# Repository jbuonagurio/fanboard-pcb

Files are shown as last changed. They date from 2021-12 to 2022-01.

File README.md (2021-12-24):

# Fan Control Board Hardware Design

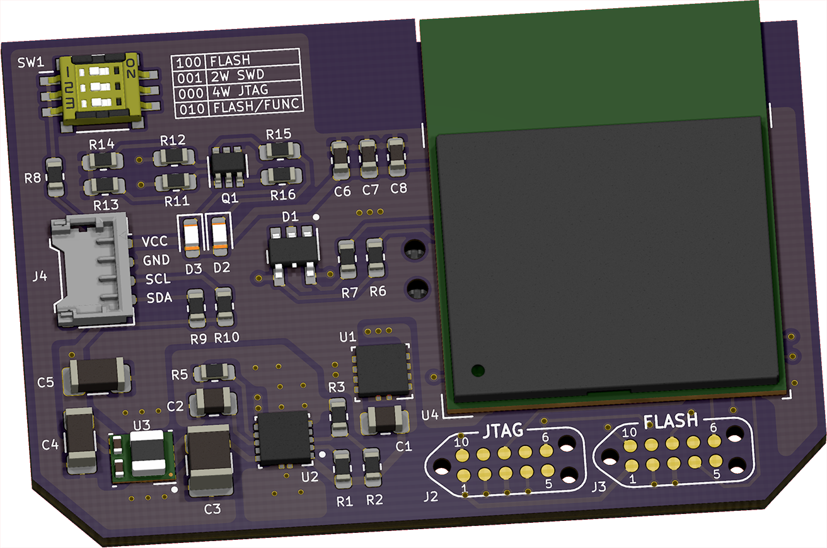
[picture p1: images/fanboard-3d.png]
3D View


## Schematic

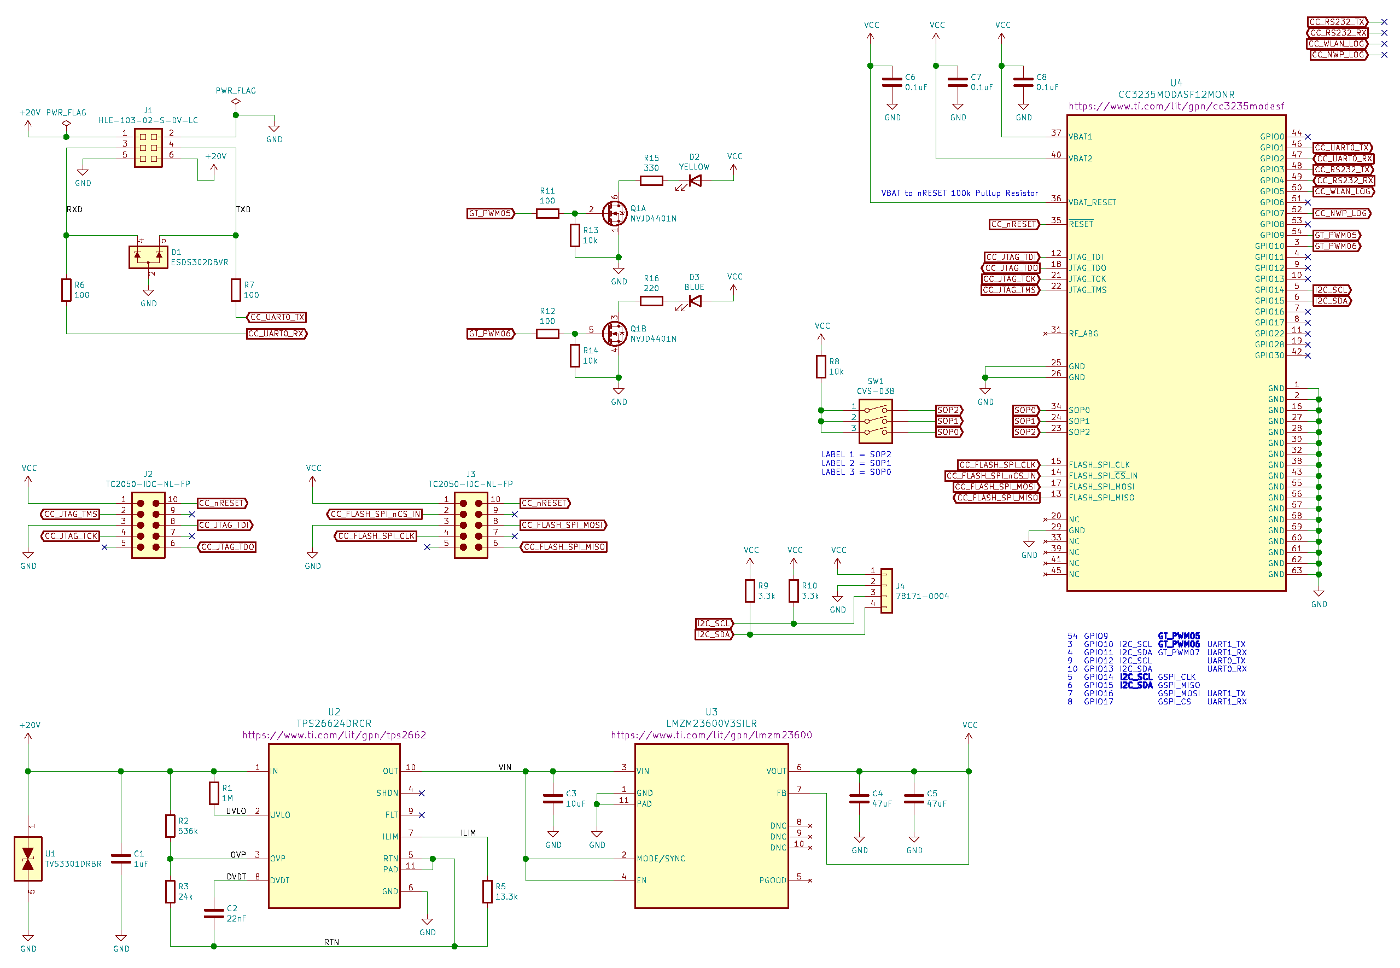
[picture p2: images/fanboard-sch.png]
Schematic


## Bill of Materials

| Designator | Quantity | Description | Manufacturer | Manufacturer Part Number | Digi-Key Part Number | 
|:---|:---:|:---|:---|:---|:---|
| SW1 | 1 | DIP Switch SPST 3 Position 1mm Pitch 100mA 6V | Nidec Copal | CVS-03TB | 563-1194-1-ND | 
| U1 | 1 | 33V Bidirectional Flat-Clamp Surge Protection Device | Texas Instruments | TVS3301DRBR | 296-53063-1-ND | 
| U2 | 1 | 60V 800mA Industrial eFuse with Integrated Input and Output Reverse Polarity Protection | Texas Instruments | TPS26624DRCR | 296-TPS26624DRCRCT-ND | 
| U3 | 1 | Non-Isolated PoL Module DC DC Converter Output 3.3V 500mA Input 4V-36V | Texas Instruments | LMZM23600V3SILT | 296-49458-1-ND | 
| U4 | 1 | Dual-Band Wireless MCU Module | Texas Instruments | CC3235MODASF12MONR | 296-CC3235MODASF12MONRCT-ND | 
| C1 | 1 | Ceramic Capacitor 1 μF 50V X7R 0805 ±10% | KEMET | C0805C105K5RACTU | 399-7409-1-ND | 
| C2 | 1 | Ceramic Capacitor 0.0022 μF (2200 pF) 50V C0G/NP0 0805 ±1% | KEMET | C0805C222F5GACTU | 399-11167-1-ND | 
| C3 | 1 | Ceramic Capacitor 10 μF 50V X7R 1210 ±10% | KEMET | C1210C106K5RACTU | 399-11629-1-ND | 
| C4 C5 | 2 | Ceramic Capacitor 47 μF 10V X5R 1206 ±20% | KEMET | C1206C476M8PACTU | 399-5508-1-ND | 
| C6 C7 C8 | 3 | Ceramic Capacitor 0.1 μF 10V X7R 0603 ±10% | KEMET | C0603C104K8RACTU | 399-1095-1-ND | 
| D1 | 1 | ESD Protection Diode Dual 2.3 pF 3.6V ±30kV SOT23-5 | Texas Instruments | ESDS302DBVR | 296-51110-1-ND | 
| D2 | 1 | Yellow 590nm LED Indication 1.85V 0603 (1608 Metric) | Kingbright | APT1608LSYCK/J3-PRV | 754-1932-1-ND | 
| D3 | 1 | Blue 470nm LED Indication 2.65V 0603 (1608 Metric) | Kingbright | APT1608LVBC/D | 754-1933-1-ND | 
| J1 	 | 1	 | HLE Socket 2.54mm Pitch 6 Position 30μ" Selective Gold Locking Clip | Samtec | HLE-103-02-S-DV-LC | HLE-103-02-S-DV-LC-ND |
| J4 | 1 | Pico-EZmate Header 1.20mm Pitch 4 Position | Molex | 078171-0004 | WM4460CT-ND | 
| Q1 | 1 | MOSFET Dual N-Channel Small Signal ESD Protection 20V 630mA SC-88 | onsemi | NVJD4401NT1G | NVJD4401NT1GOSCT-ND | 
| R1 | 1 | Resistor 1 MΩ 1/10W 0603 ±0.5% Thin Film | Yageo | RT0603DRD071ML | 13-RT0603DRD071MLCT-ND | 
| R9 R10 | 2 | Resistor 3.3 kΩ 1/10W 0603 ±5% | Vishay Dale | CRCW06033K30JNEAC | 541-CRCW06033K30JNEACCT-ND  | 
| R15 | 1 | Resistor 330 Ω 1/10W 0603 ±1% | Vishay Dale | CRCW0603330RFKEA | 541-330HCT-ND | 
| R16 | 1 | Resistor 220 Ω 1/10W 0603 ±1% | Vishay Dale | CRCW0603220RJNEA | 541-220GCT-ND | 
| R2 | 1 | Resistor 536 kΩ 1/10W 0603 ±0.1% Thin Film | Yageo | RT0603BRD07536KL | 13-RT0603BRD07536KLCT-ND | 
| R3 | 1 | Resistor 24 kΩ 1/10W 0603 ±0.5% Thin Film | Yageo | RT0603DRD0724KL | 311-24KDCT-ND | 
| R5 | 1 | Resistor 13.3 kΩ 1/10W 0603 ±0.5% Thin Film | Yageo | RT0603DRD0713K3L | 311-13.3KDCT-ND | 
| R6 R7 R11 R12 | 4 | Resistor 100 Ω 1/10W 0603 ±1% | Vishay Dale | CRCW0603100RFKEAC | 541-3951-1-ND | 
| R8 R13 R14 | 3 | Resistor 10 kΩ 1/10W 0603 ±1% | Vishay Dale | CRCW060310K0FKEAC | 541-5136-1-ND |

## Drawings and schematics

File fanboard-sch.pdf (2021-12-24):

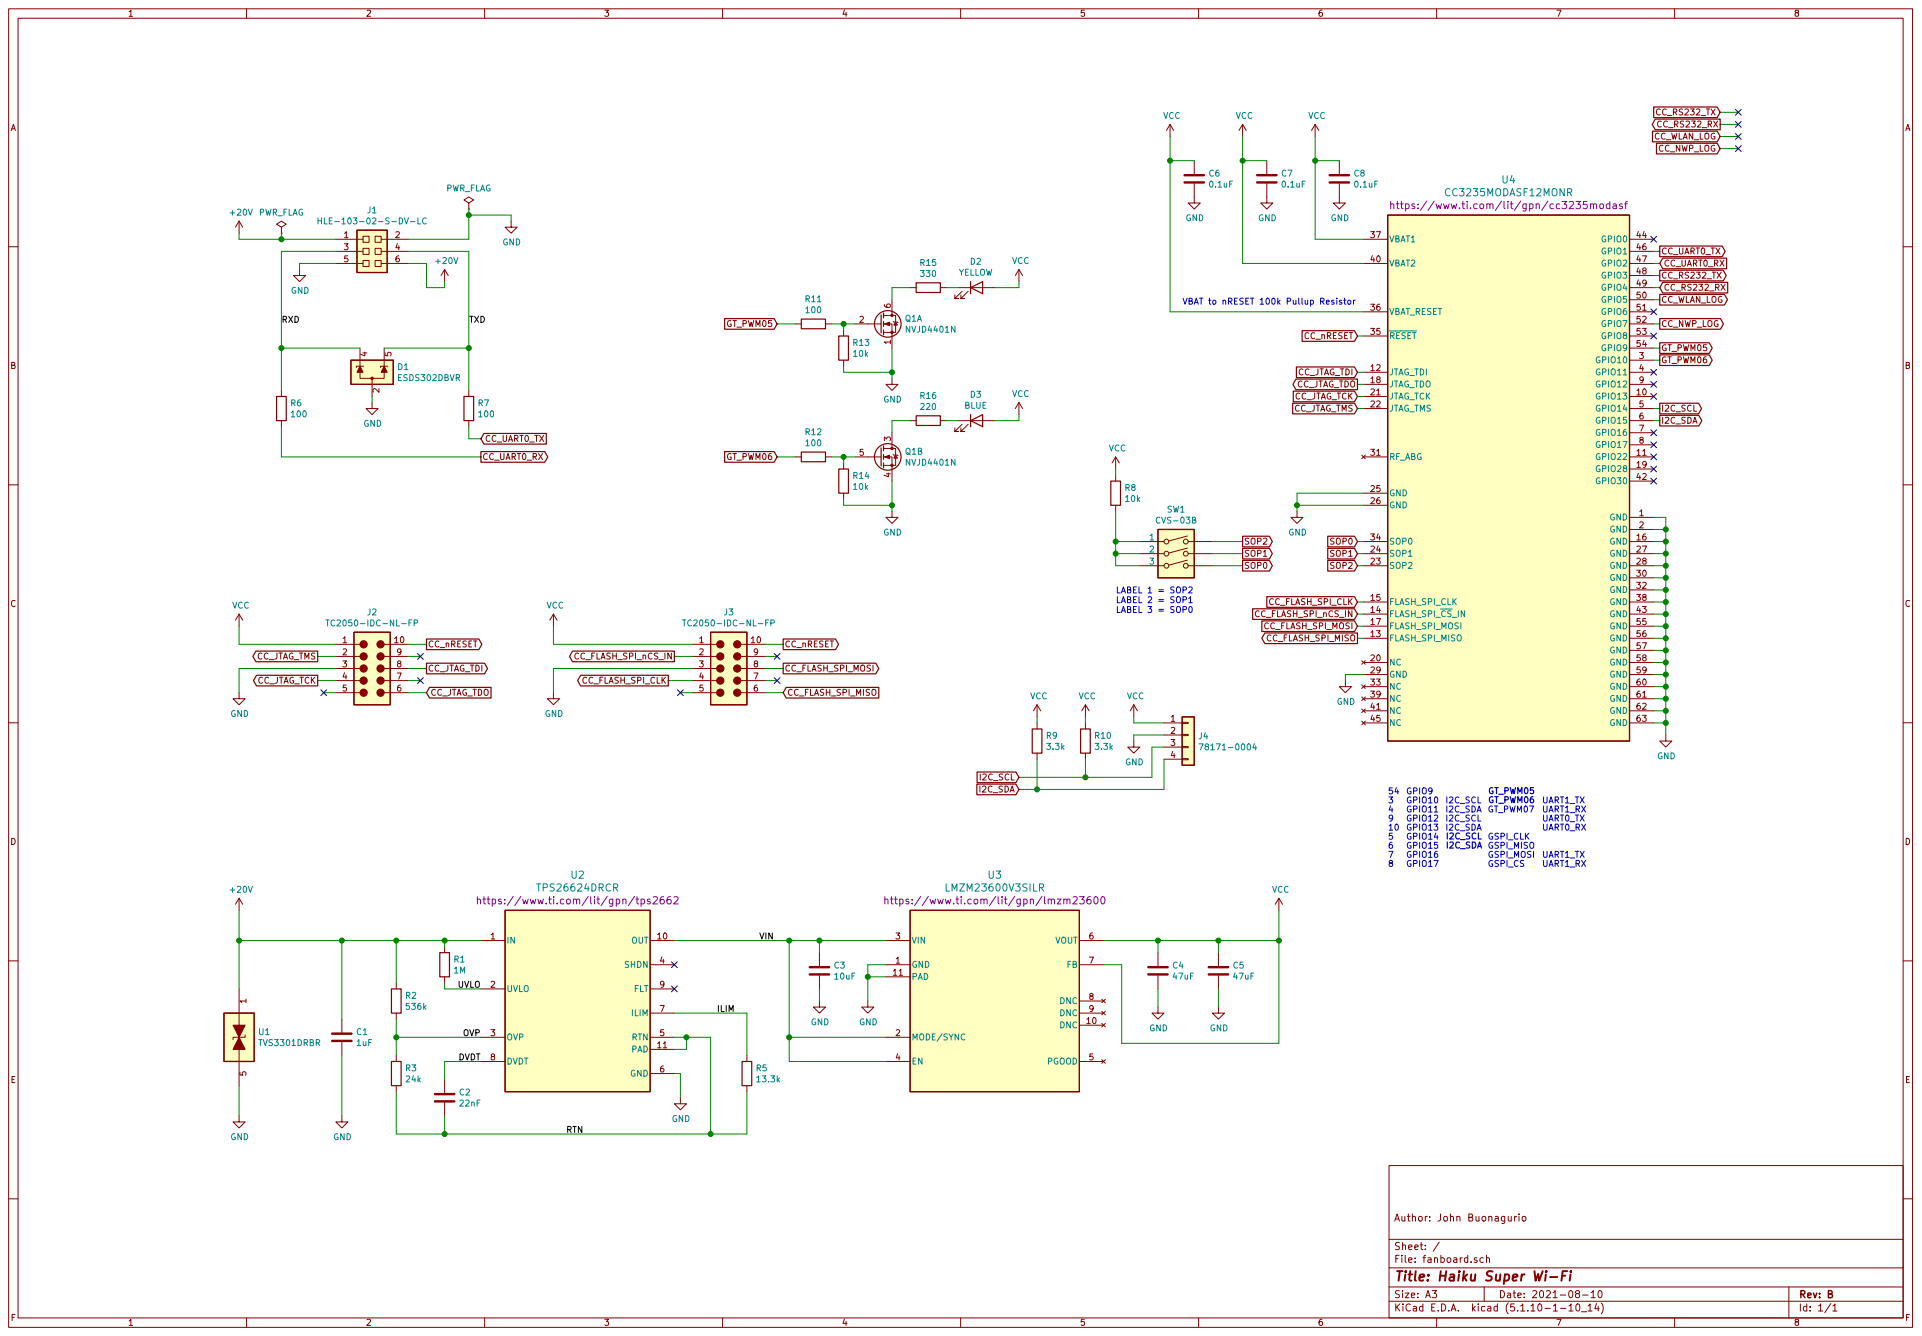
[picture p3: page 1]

https://www.ti.com/lit/gpn/cc3235modasf

VBAT to nRESET 100k Pullup Resistor

Id: 1/1 Title: Haiku Super Wi-Fi File: fanboard.sch Sheet: / Author: John Buonagurio VCC

https://www.ti.com/lit/gpn/tps2662

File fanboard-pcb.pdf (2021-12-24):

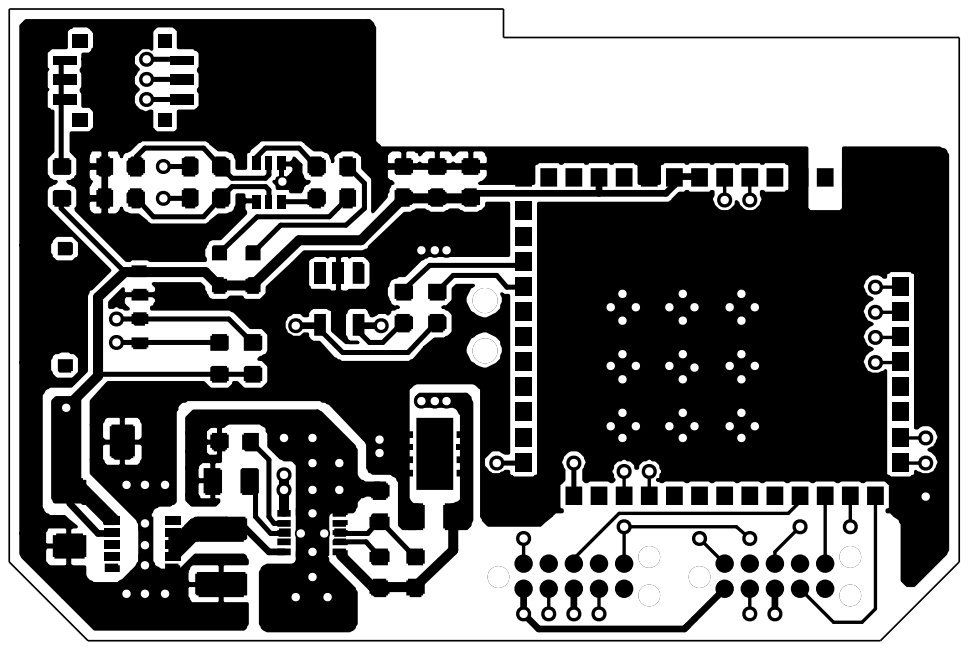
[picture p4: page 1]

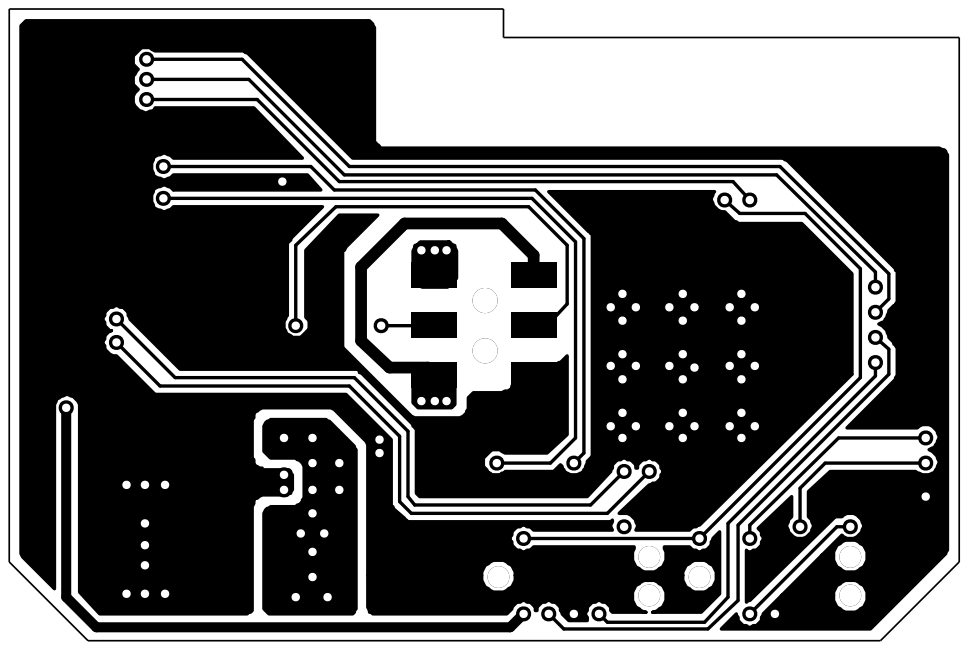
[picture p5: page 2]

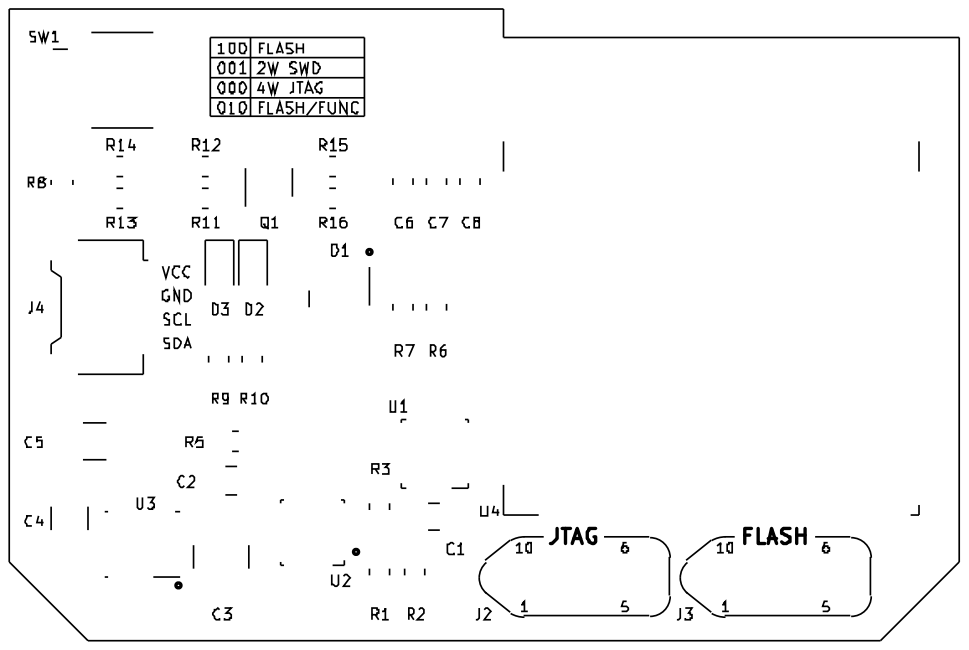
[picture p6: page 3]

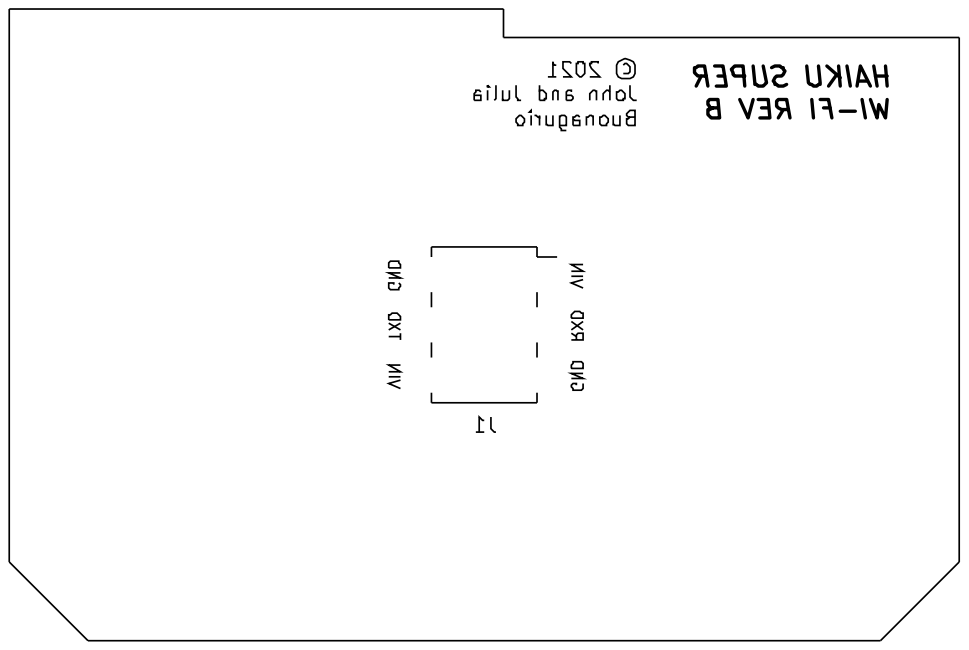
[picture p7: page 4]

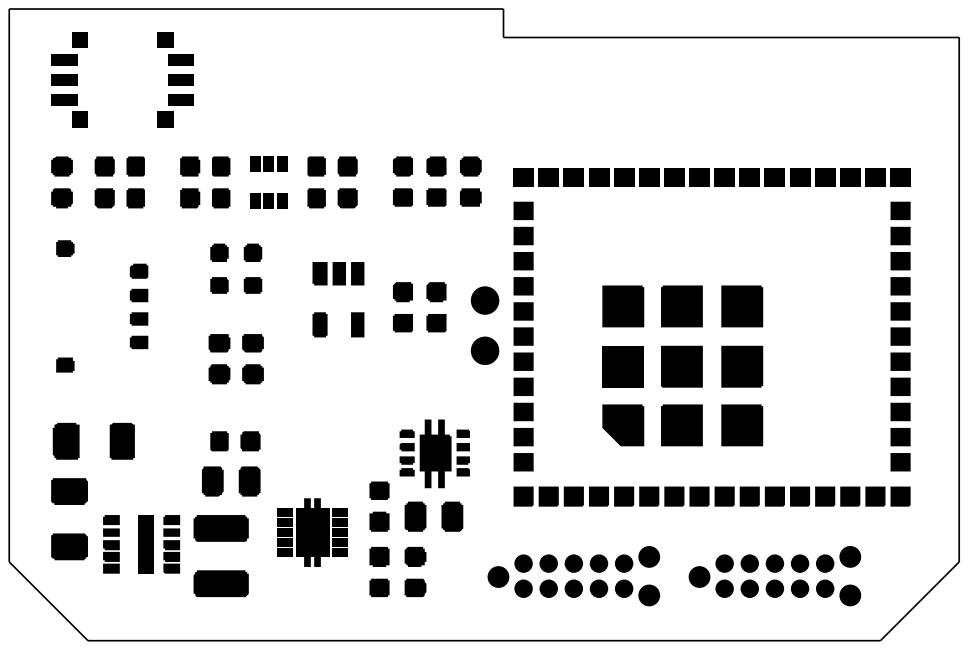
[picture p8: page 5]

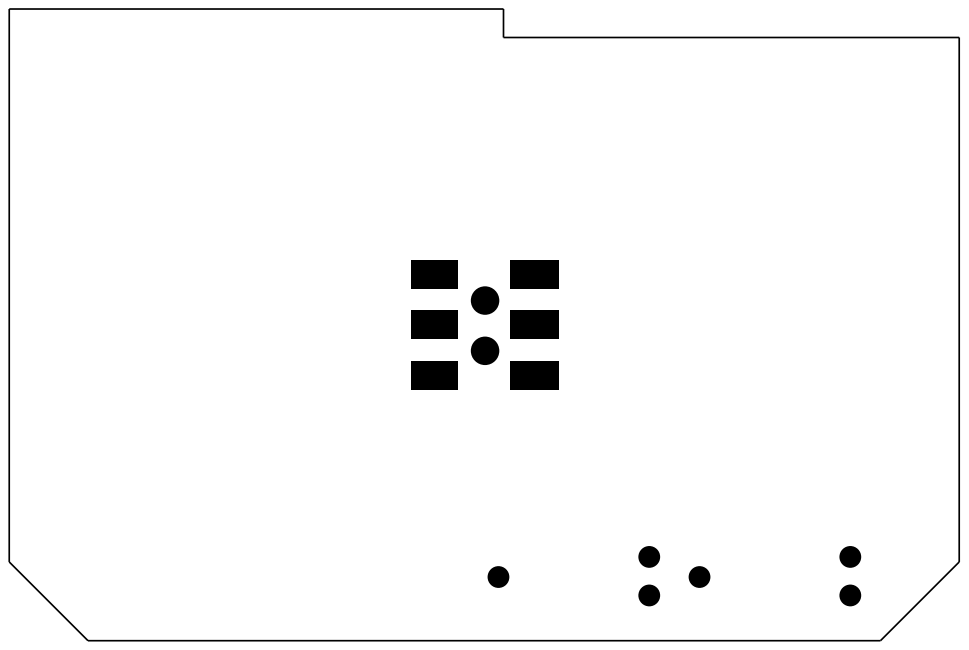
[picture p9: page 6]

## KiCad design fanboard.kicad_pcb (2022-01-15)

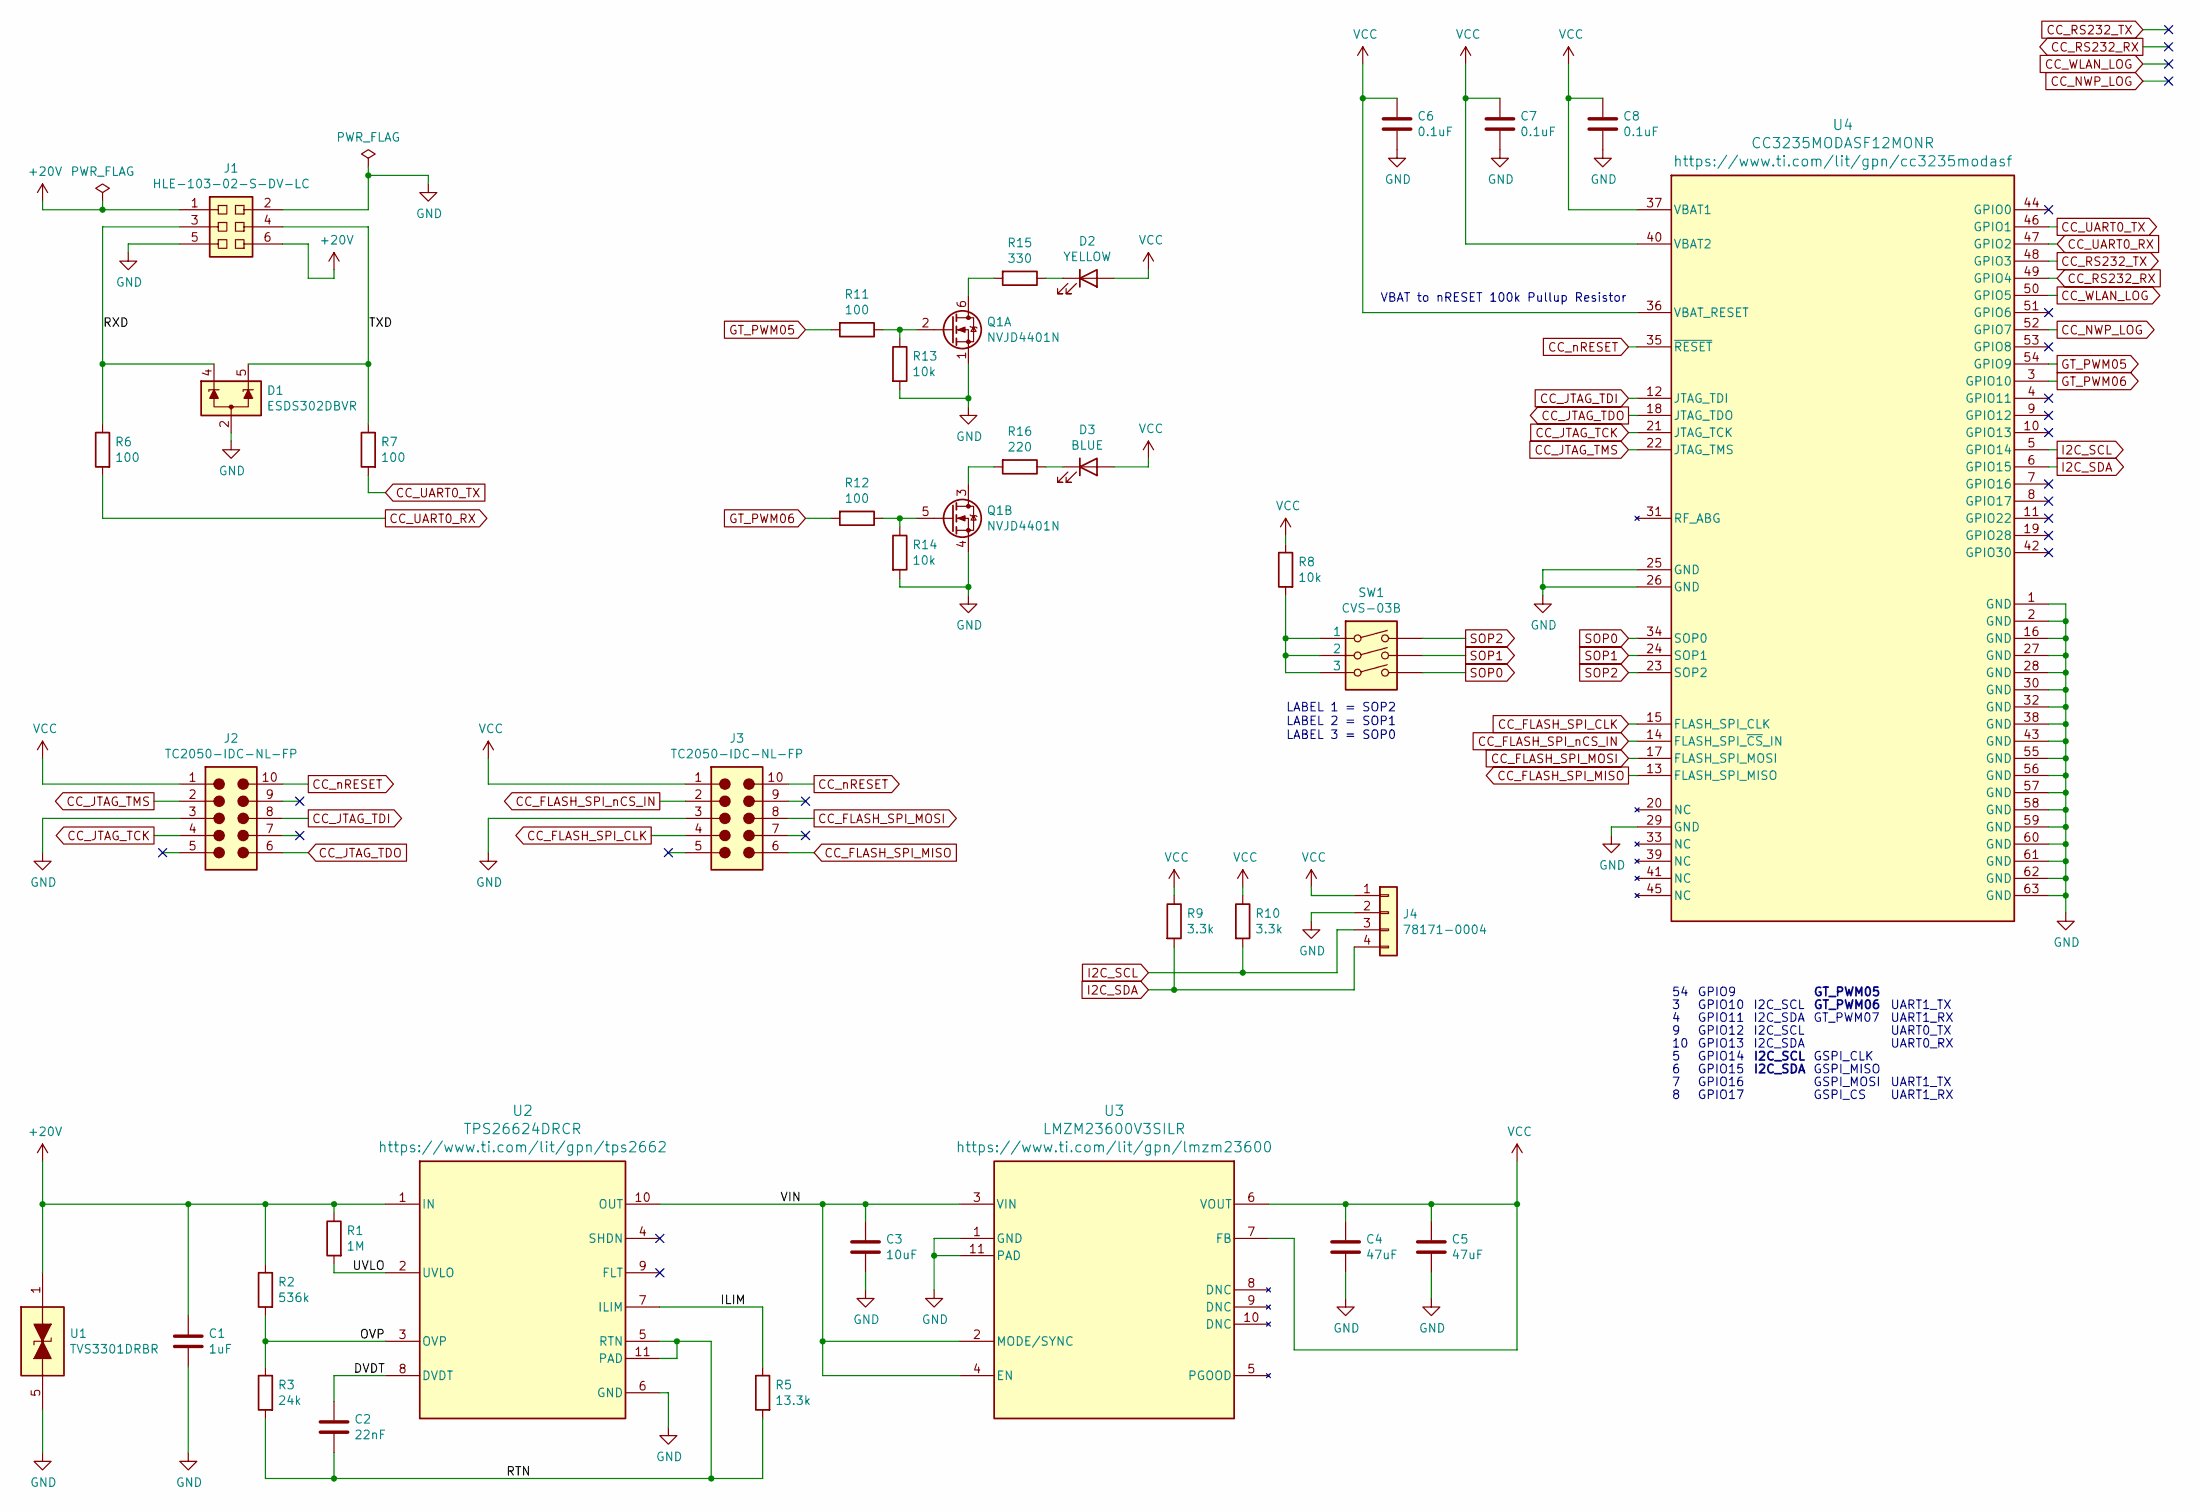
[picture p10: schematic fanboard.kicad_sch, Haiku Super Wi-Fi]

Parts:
C1: 1uF; C_0805_2012Metric
C2: 22nF; C_0805_2012Metric
C3: 10uF; C_1210_3225Metric
C4, C5: 47uF; C_1206_3216Metric
C6, C7, C8: 0.1uF; C_0603_1608Metric
D1: ESDS302DBVR; DBV0005A
D2: YELLOW; APT1608
D3: BLUE; APT1608
J1: HLE-103-02-S-DV-LC
J2: TC2050-IDC-NL-FP; TC2050-IDC-NL-FP-JTAG
J3: TC2050-IDC-NL-FP; TC2050-IDC-NL-FP-Flash
J4: 78171-0004
Q1: NVJD4401N; 419B-02
R1: 1M; R_0603_1608Metric
R2: 536k; R_0603_1608Metric
R3: 24k; R_0603_1608Metric
R5: 13.3k; R_0603_1608Metric
R6, R7, R11, R12: 100; R_0603_1608Metric
R8, R13, R14: 10k; R_0603_1608Metric
R9, R10: 3.3k; R_0603_1608Metric
R15: 330; R_0603_1608Metric
R16: 220; R_0603_1608Metric
SW1: CVS-03B
U1: TVS3301DRBR; DRB0008A
U2: TPS26624DRCR; DRC0010J
U3: LMZM23600V3SILR; SIL0010A
U4: CC3235MODASF12MONR; MON0063A

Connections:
+20V: C1.1, J1.1, J1.6, R1.1, R2.1, U1.1 (IN), U1.2 (IN), U1.3 (IN), U1.4 (IN), U2.1 (IN)
/DVDT: C2.1, U2.8 (DVDT)
/ILIM: R5.1, U2.7 (ILIM)
/OVP: R2.2, R3.1, U2.3 (OVP)
/RTN: C2.2, R3.2, R5.2, U2.5 (RTN), U2.11 (PAD)
/RXD: D1.4 (I/O2), J1.3, R6.1
/TXD: D1.5 (I/O1), J1.4, R7.1
/UVLO: R1.2, U2.2 (UVLO)
/VIN: C3.1, U2.10 (OUT), U3.2 (MODE/SYNC), U3.3 (VIN), U3.4 (EN)
CC_FLASH_SPI_CLK: J3.4, U4.15 (FLASH_SPI_CLK)
CC_FLASH_SPI_MISO: J3.6, U4.13 (FLASH_SPI_MISO)
CC_FLASH_SPI_MOSI: J3.8, U4.17 (FLASH_SPI_MOSI)
CC_FLASH_SPI_nCS_IN: J3.2, U4.14 (FLASH_SPI_~CS_IN)
CC_JTAG_TCK: J2.4, U4.21 (JTAG_TCK)
CC_JTAG_TDI: J2.8, U4.12 (JTAG_TDI)
CC_JTAG_TDO: J2.6, U4.18 (JTAG_TDO)
CC_JTAG_TMS: J2.2, U4.22 (JTAG_TMS)
CC_NWP_LOG: U4.52 (GPIO7)
CC_RS232_RX: U4.49 (GPIO4)
CC_RS232_TX: U4.48 (GPIO3)
CC_UART0_RX: R6.2, U4.47 (GPIO2)
CC_UART0_TX: R7.2, U4.46 (GPIO1)
CC_WLAN_LOG: U4.50 (GPIO5)
CC_nRESET: J2.10, J3.10, U4.35 (~RESET)
GND: C1.2, C3.2, C4.2, C5.2, C6.2, C7.2, C8.2, D1.2 (GND), J1.2, J1.5, J2.3, J3.3, J4.2, Q1.1 (S), Q1.4 (S), R13.2, R14.2, U1.5 (GND), U1.6 (GND), U1.7 (GND), U1.8 (GND), U2.6 (GND), U3.1 (GND), U3.11 (PAD), U4.1 (GND), U4.2 (GND), U4.16 (GND), U4.25 (GND), U4.26 (GND), U4.27 (GND), U4.28 (GND), U4.29 (GND), U4.30 (GND), U4.32 (GND), U4.38 (GND), U4.43 (GND), U4.55 (GND), U4.56 (GND), U4.57 (GND), U4.58 (GND), U4.59 (GND), U4.60 (GND), U4.61 (GND), U4.62 (GND), U4.63 (GND)
GT_PWM05: R11.2, U4.54 (GPIO9)
GT_PWM06: R12.2, U4.3 (GPIO10)
I2C_SCL: J4.3, R10.2, U4.5 (GPIO14)
I2C_SDA: J4.4, R9.2, U4.6 (GPIO15)
unnamed: D2.1 (K), R15.1
unnamed: D3.1 (K), R16.1
unnamed: Q1.2 (G), R11.1, R13.1
unnamed: Q1.3 (D), R16.2
unnamed: Q1.5 (G), R12.1, R14.1
unnamed: Q1.6 (D), R15.2
unnamed: R8.2, SW1.1, SW1.2, SW1.3
SOP0: SW1.4, U4.34 (SOP0)
SOP1: SW1.5, U4.24 (SOP1)
SOP2: SW1.6, U4.23 (SOP2)
VCC: C4.1, C5.1, C6.1, C7.1, C8.1, D2.2 (A), D3.2 (A), J2.1, J3.1, J4.1, R8.1, R9.1, R10.1, U3.6 (VOUT), U3.7 (FB), U4.36 (VBAT_RESET), U4.37 (VBAT1), U4.40 (VBAT2)

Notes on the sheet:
GPIO14
UART1_RX
GSPI_CS
GSPI_MISO
GT_PWM07
GPIO10
UART0_RX
GPIO16
GPIO11
I2C_SCL
I2C_SDA
GT_PWM06
UART1_TX
GSPI_MOSI
VBAT to nRESET 100k Pullup Resistor
GPIO15
GPIO12
UART0_TX
GPIO17
LABEL 1 = SOP2 LABEL 2 = SOP1 LABEL 3 = SOP0
GSPI_CLK
GPIO9
GT_PWM05
GPIO13

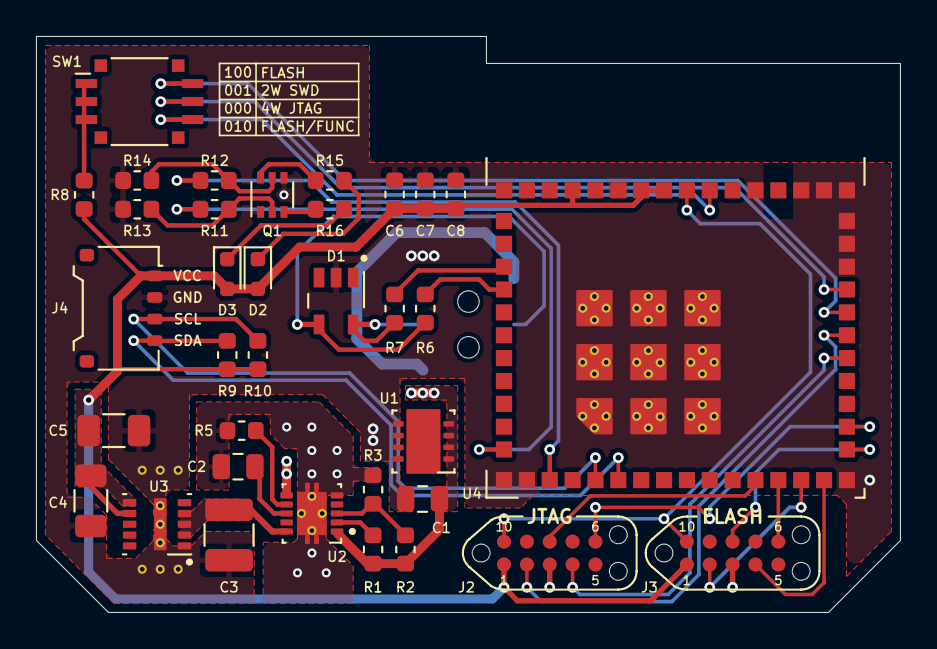
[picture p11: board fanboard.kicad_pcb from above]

Board: 2 copper layers, 48.0 x 32.0 mm, 36 parts (1 on the bottom side), 36 nets.

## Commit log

2021-12-24 First commit
    First commit
    [fanboard-B_Cu.gbl, fanboard-B_Mask.gbs, fanboard-B_Paste.gbp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]
2022-01-15 Update to KiCad 6; add additional manufacturer STEP files.
    [fanboard.kicad_pcb, fanboard.kicad_sch, fanboard.sch]

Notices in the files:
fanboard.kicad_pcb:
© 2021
